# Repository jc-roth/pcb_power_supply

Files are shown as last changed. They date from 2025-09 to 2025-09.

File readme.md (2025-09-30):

# pcb_power_supply
This repository contains the KiCAD schematic/PCB files for a linear and switching power supply board that can be used to power boards using the template in [this repo](https://github.com/jc-roth/pcb_kicad_template).

## Building/operating the circuit
Either directly download gerber and BOM files from the releases page or download the KiCAD project and export to your liking. Feel free to shoot me an email with any questions.

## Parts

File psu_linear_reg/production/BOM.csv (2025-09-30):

Reference | Value | Datasheet | Footprint | Qty | DNP | Digikey PN | JLCPCB PN
C1,C9 | 330n | ~ | Capacitor_SMD:C_0805_2012Metric_Pad1.18x1.45mm_HandSolder | 2 |  |  | C1740
C2,C11 | 100n | ~ | Capacitor_SMD:C_0805_2012Metric_Pad1.18x1.45mm_HandSolder | 2 |  |  | C49678
C3,C10 | 2.2u | ~ | Capacitor_THT:CP_Radial_D6.3mm_P2.50mm | 2
C4,C12 | 1u | ~ | Capacitor_THT:CP_Radial_D6.3mm_P2.50mm | 2
HS1,HS2,HS3,HS4 | Heatsink | ~ |  | 4 |  | 345-1023-ND
J1,J2 | Conn_Coaxial_Power | ~ | matterwaves:BNC_Molex_0731385033 | 2 |  | ACX1971-ND
J3,J4,J5,J6 | Conn_01x10_Pin | ~ | Connector_JST:JST_ZH_B10B-ZR_1x10_P1.50mm_Vertical | 4 |  | 455-S10B-ZR-ND
U1 | L7805 | http://www.st.com/content/ccc/resource/technical/document/datasheet/41/4f/b3/b0/12/d4/47/88/CD00000444.pdf/files/CD00000444.pdf/jcr:content/translations/en.CD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 | Package_TO_SOT_THT:TO-220-3_Vertical | 1 |  | 497-1443-5-ND
U2 | L7905 | http://www.st.com/content/ccc/resource/technical/document/datasheet/c9/16/86/41/c7/2b/45/f2/CD00000450.pdf/files/CD00000450.pdf/jcr:content/translations/en.CD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 | Package_TO_SOT_THT:TO-220-3_Vertical | 1 |  | 497-12408-ND
U3 | L7812 | http://www.st.com/content/ccc/resource/technical/document/datasheet/41/4f/b3/b0/12/d4/47/88/CD00000444.pdf/files/CD00000444.pdf/jcr:content/translations/en.CD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 | Package_TO_SOT_THT:TO-220-3_Vertical | 1 |  | 497-13138-ND
U4 | L7912 | http://www.st.com/content/ccc/resource/technical/document/datasheet/c9/16/86/41/c7/2b/45/f2/CD00000450.pdf/files/CD00000450.pdf/jcr:content/translations/en.CD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 | Package_TO_SOT_THT:TO-220-3_Vertical | 1 |  | 497-1476-5-ND

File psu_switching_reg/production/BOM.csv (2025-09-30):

Reference | Value | Datasheet | Footprint | Qty | DNP | Digikey PN | JLCPCB PN
C1,C2,C3,C4,C5,C6,C7,C8 | 10u | ~ | Capacitor_SMD:C_0805_2012Metric_Pad1.18x1.45mm_HandSolder | 8 |  |  | C440198
H1,H2 | Keystone Electronics 621 | ~ | matterwaves:Keystone 621 | 2 |  | 36-621-ND
J1 | Conn_Coaxial_Power | ~ | matterwaves:CUI_PJ-037B | 1 |  | CP-037B-ND
J2,J3,J4,J5 | Conn_01x10_Pin | ~ | Connector_JST:JST_ZH_B10B-ZR_1x10_P1.50mm_Vertical | 4 |  | 455-S10B-ZR-ND
L1,L2 | 4.7u | ~ | Inductor_THT:L_Axial_L7.0mm_D3.3mm_P2.54mm_Vertical_Fastron_MICC | 2 |  | 535-AIAP-01-4R7K-TCT-ND
U1,U2 | R-78B5.0-2.0 | https://g.recomcdn.com/media/Datasheet/pdf/.fldP_2rX/.t124a6889b0e40eeb9ac1/Datasheet-285/R-78B-2_0.pdf | matterwaves:R-78Bxx-2.0 | 2 |  | 945-3042-ND
U3,U4 | R-78B12-2.0 | https://g.recomcdn.com/media/Datasheet/pdf/.fldP_2rX/.t124a6889b0e40eeb9ac1/Datasheet-285/R-78B-2_0.pdf | matterwaves:R-78Bxx-2.0 | 2 |  | 945-3041-ND

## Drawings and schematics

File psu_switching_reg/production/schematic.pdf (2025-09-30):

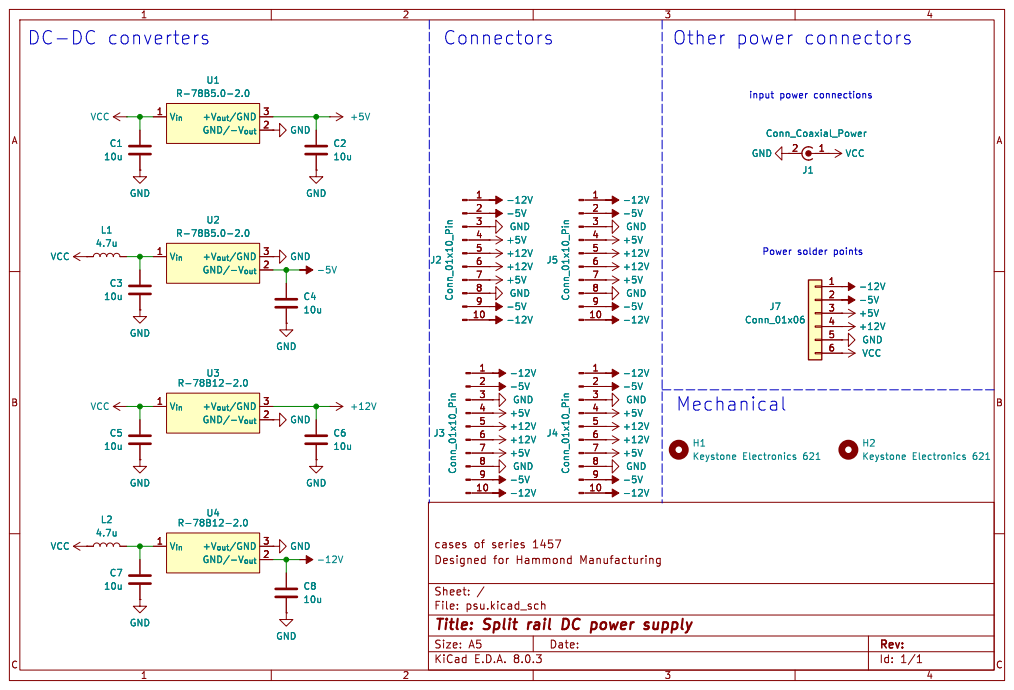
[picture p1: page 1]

Id: 1/1 Title: Split rail DC power supply

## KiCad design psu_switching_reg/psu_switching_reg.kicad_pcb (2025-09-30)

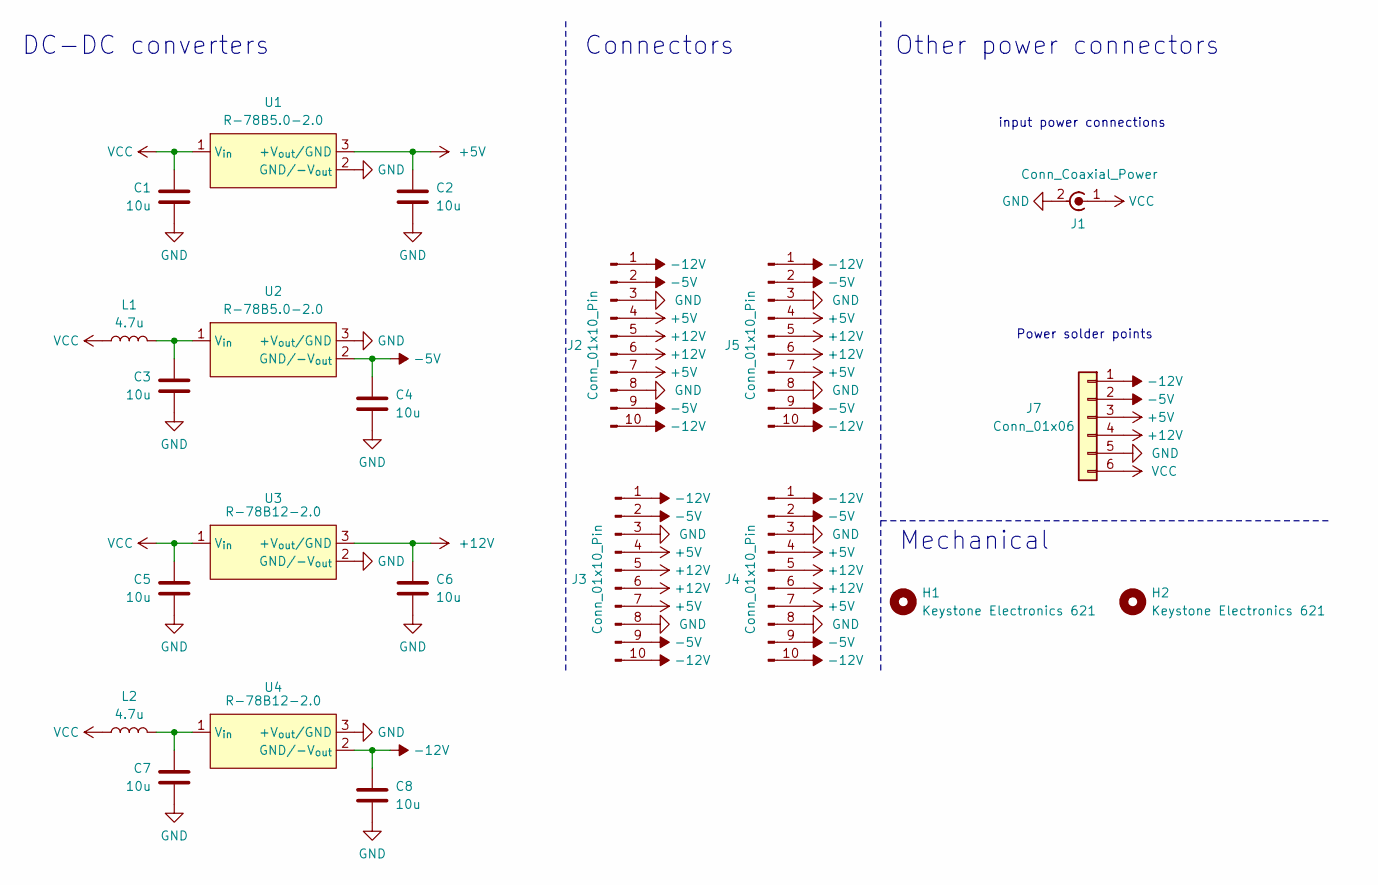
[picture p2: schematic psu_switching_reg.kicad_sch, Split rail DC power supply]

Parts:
C1, C2, C3, C4, C5, C6, C7, C8: 10u; C_0805_2012Metric_Pad1.18x1.45mm_HandSolder; JLCPCB PN C440198
H1, H2: Keystone Electronics 621; Keystone 621; Digikey PN 36-621-ND
J1: Conn_Coaxial_Power; CUI_PJ-037B; Digikey PN CP-037B-ND
J2, J3, J4, J5: Conn_01x10_Pin; JST_ZH_B10B-ZR_1x10_P1.50mm_Vertical; Digikey PN 455-S10B-ZR-ND
J7: Conn_01x06; SolderWire-1sqmm_1x06_P5.4mm_D1.4mm_OD2.7mm
L1, L2: 4.7u; L_Axial_L7.0mm_D3.3mm_P2.54mm_Vertical_Fastron_MICC; Digikey PN 535-AIAP-01-4R7K-TCT-ND
U1, U2: R-78B5.0-2.0; R-78Bxx-2.0; Digikey PN 945-3042-ND
U3, U4: R-78B12-2.0; R-78Bxx-2.0; Digikey PN 945-3041-ND

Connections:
+5V: C2.1, J2.4, J2.7, J3.4, J3.7, J4.4, J4.7, J5.4, J5.7, J7.3, U1.3 (+V_{out}/GND)
+12V: C6.1, J2.5, J2.6, J3.5, J3.6, J4.5, J4.6, J5.5, J5.6, J7.4, U3.3 (+V_{out}/GND)
-5V: C4.1, J2.2, J2.9, J3.2, J3.9, J4.2, J4.9, J5.2, J5.9, J7.2, U2.2 (GND/-V_{out})
-12V: C8.1, J2.1, J2.10, J3.1, J3.10, J4.1, J4.10, J5.1, J5.10, J7.1, U4.2 (GND/-V_{out})
GND: C1.2, C2.2, C3.2, C4.2, C5.2, C6.2, C7.2, C8.2, J1.2 (Ext), J2.3, J2.8, J3.3, J3.8, J4.3, J4.8, J5.3, J5.8, J7.5, U1.2 (GND/-V_{out}), U2.3 (+V_{out}/GND), U3.2 (GND/-V_{out}), U4.3 (+V_{out}/GND)
unnamed: C3.1, L1.2, U2.1 (V_{in})
unnamed: C7.1, L2.2, U4.1 (V_{in})
VCC: C1.1, C5.1, J1.1 (In), J7.6, L1.1, L2.1, U1.1 (V_{in}), U3.1 (V_{in})

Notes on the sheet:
Other power connectors
Power solder points
input power connections
Mechanical
DC-DC converters
Connectors

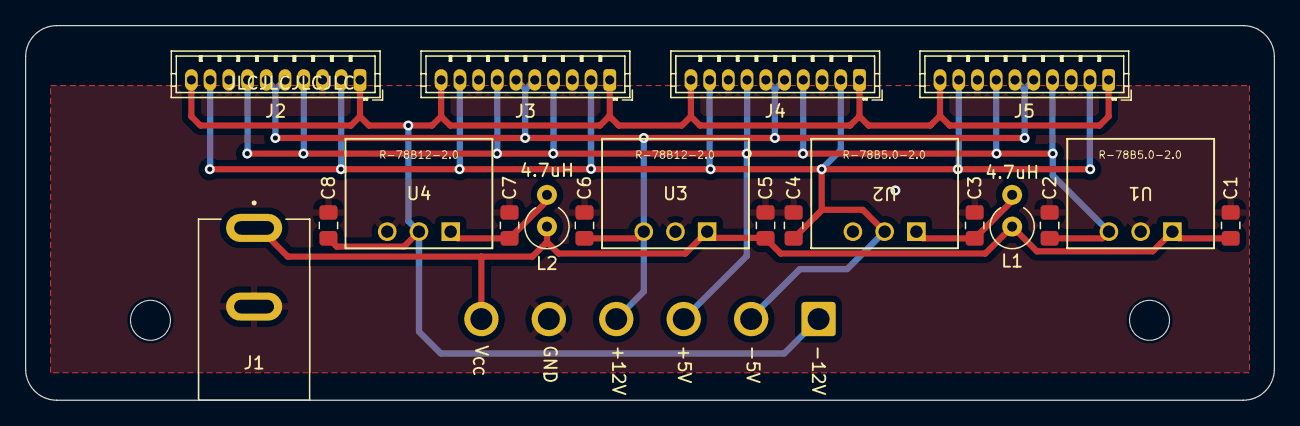
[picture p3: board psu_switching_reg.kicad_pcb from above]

Board: 2 copper layers, 100.0 x 30.0 mm, 22 parts (0 on the bottom side), 8 nets.

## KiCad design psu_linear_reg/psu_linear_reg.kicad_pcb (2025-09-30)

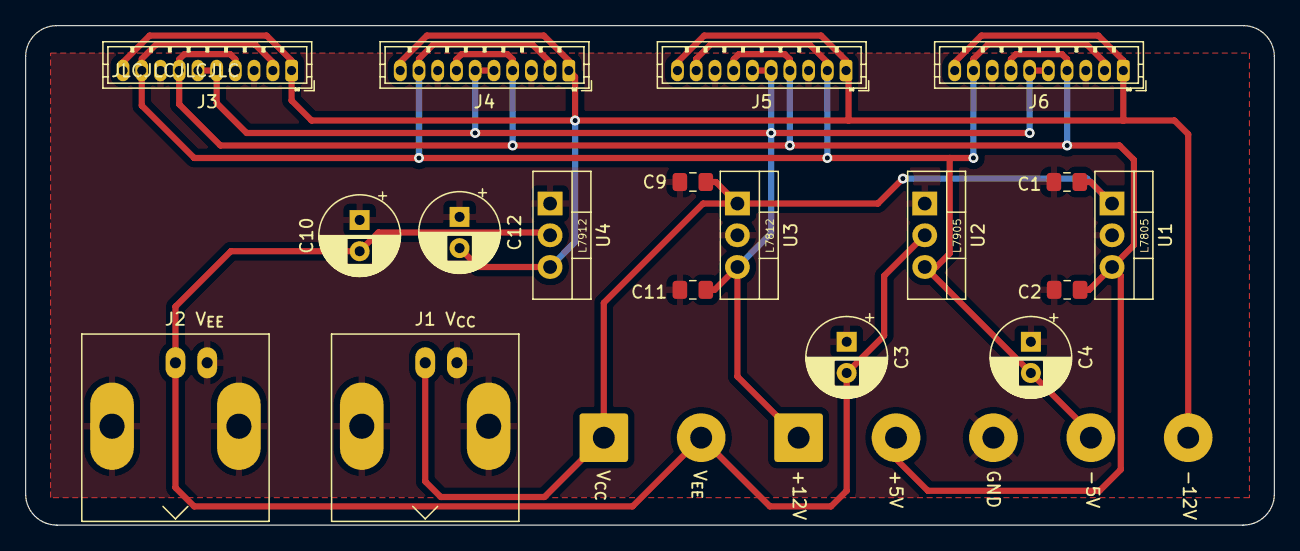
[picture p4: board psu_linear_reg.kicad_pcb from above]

Board: 2 copper layers, 100.0 x 40.0 mm, 20 parts (0 on the bottom side), 7 nets.

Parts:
C1, C9: 330n; C_0805_2012Metric_Pad1.18x1.45mm_HandSolder
C2, C11: 100n; C_0805_2012Metric_Pad1.18x1.45mm_HandSolder
C3, C10: 2.2u; CP_Radial_D6.3mm_P2.50mm
C4, C12: 1u; CP_Radial_D6.3mm_P2.50mm
J1, J2: Conn_Coaxial_Power; BNC_Molex_0731385033
J3, J4, J5, J6: Conn_01x10_Pin; JST_ZH_B10B-ZR_1x10_P1.50mm_Vertical
J7: Conn_01x05; SolderWire-1sqmm_1x05_P7.8mm_D1.4mm_OD3.9mm
J8: Conn_01x02; SolderWire-1sqmm_1x02_P7.8mm_D1.4mm_OD3.9mm
U1: L7805; TO-220-3_Vertical
U2: L7905; TO-220-3_Vertical
U3: L7812; TO-220-3_Vertical
U4: L7912; TO-220-3_Vertical

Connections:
+5V: C2.1, J3.4, J3.7, J4.4, J4.7, J5.4, J5.7, J6.4, J6.7, J7.2, U1.3 (OUT)
+12V: C11.1, J3.5, J3.6, J4.5, J4.6, J5.5, J5.6, J6.5, J6.6, J7.1, U3.3 (OUT)
-5V: C4.2, J3.2, J3.9, J4.2, J4.9, J5.2, J5.9, J6.2, J6.9, J7.4, U2.3 (VO)
-12V: C12.2, J3.1, J3.10, J4.1, J4.10, J5.1, J5.10, J6.1, J6.10, J7.5, U4.3 (VO)
GND: C1.2, C2.2, C3.1, C4.1, C9.2, C10.1, C11.2, C12.1, J1.2 (Ext), J2.2 (Ext), J3.3, J3.8, J4.3, J4.8, J5.3, J5.8, J6.3, J6.8, J7.3, U1.2 (GND), U2.1 (GND), U3.2 (GND), U4.1 (GND)
VCC: C1.1, C9.1, J1.1 (In), J8.1, U1.1 (IN), U3.1 (IN)
VEE: C3.2, C10.2, J2.1 (In), J8.2, U2.2 (VI), U4.2 (VI)
